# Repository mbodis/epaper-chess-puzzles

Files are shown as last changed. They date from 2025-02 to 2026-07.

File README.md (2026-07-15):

## Chess Puzzle Box with E-Paper Display
This project is a compact, battery-efficient chess puzzle box that uses an e-paper display and a push-button power switch for minimal power consumption. Puzzles are sourced from the Lichess puzzle database.

### Usage:

* First click: Shows a chess puzzle.
* Second click: Reveals the solution.

Perfect for practicing chess tactics on the go, with long battery life thanks to the low-power design.

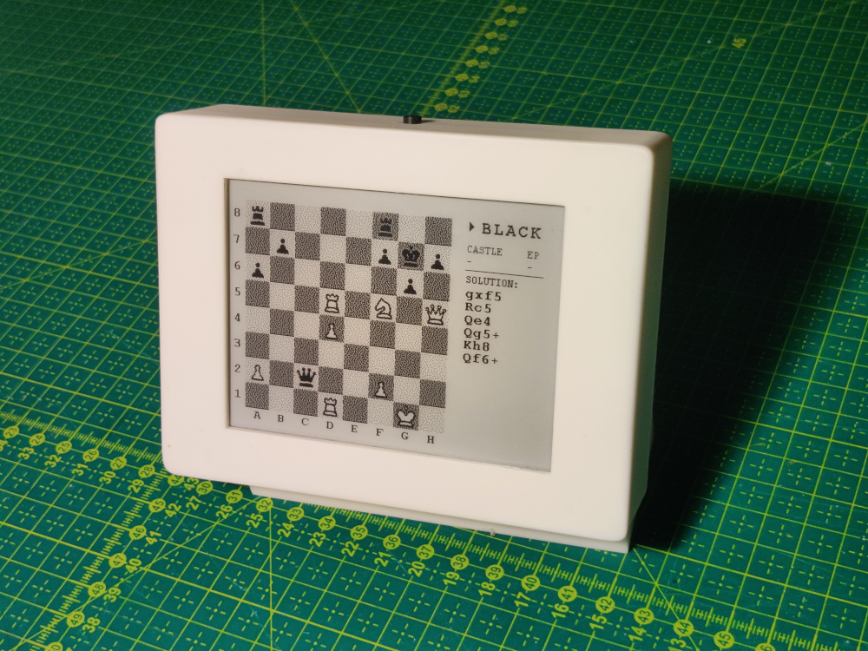
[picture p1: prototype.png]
image of chess box


## hardware setup

---
- 3.7 LiPo battery 
- 4.2 epaper wave share: https://www.waveshare.com/4.2inch-e-paper-module.htm
- adafruit logger RP2040: https://learn.adafruit.com/adafruit-feather-rp2040-adalogger/overview
- adafruit push-button power switch: https://www.adafruit.com/product/1400
- jump wires

## setup:

---
1. install arduino IDE https://www.arduino.cc/
2. install RP2040 board https://learn.adafruit.com/adafruit-feather-rp2040-adalogger/arduino (version 4.4.1)
3. install library for sd card: https://learn.adafruit.com/adafruit-feather-rp2040-adalogger/sd-card-2   
   - (note: 32 GB not working, 8GB working correctly)
4. setup epaper library (two options):

   **Option 1: Use included library (recommended)**
   - library supports **BOTH** 4.2" e-paper V1 and V2 displays
   - create symlink: `ln -s /path/to/repo/lib ~/Documents/Arduino/libraries/EPD4in2`
   - GPIO config is already set in `lib/DEV_Config.h` for Adalogger RP2040
   - to use V2 display, uncomment `#define USE_EPAPER_V2` in `ChessPuzzle.h`

   **Option 2: Download manually**
   - library supports **ONLY** 4.2" e-paper V1 displays
   - download from: https://www.waveshare.com/wiki/E-Paper_ESP8266_Driver_Board
   - copy into `~/Documents/Arduino/libraries/EPD4in2`
   - update `DEV_Config.h` to match board:
     ```
     // GPIO config Adalogger RP2040 with 4.2 waveshare epaper
     #define EPD_SCK_PIN  14
     #define EPD_MOSI_PIN 15
     #define EPD_CS_PIN   9
     #define EPD_RST_PIN  11
     #define EPD_DC_PIN   27
     #define EPD_BUSY_PIN 2
     ```
5. wire by attached scheme
6. install Python chess library for UCI to SAN conversion:
   ```bash
   pip3 install chess
   ```
7. generate puzzles and config by running `generate-puzzles.sh` (this will create puzzles and config in sd-card folder)
   - by default converts UCI notation to SAN notation (e.g., "e2e4" → "e4")
   - to skip conversion and keep UCI format: `./generate-puzzles.sh 1000 100 false`
   - copy content of sd-card folder into memory card (root folder)
8. select proper board and port in Arduino IDE
9. upload and enjoy

## SD card:

---
  - should contain `config.txt` file with two numbers. First is the number of lines. Second number of files.
  - should contain `counter.txt` file with one number. For beginnig it should be set to zero. Keep position in puzzles.
  - list of puzzles accordingly to config files puzzle-1.csv, puzzle-2.csv ... 
  - `solution.txt` is created automatically by the device after a puzzle is shown. It holds the current puzzle (in CSV format compatible with `puzzle-*.csv`) so that the next power-on can render the solution view. It is removed automatically after the solution is shown.

## how it works (two-boot flow):

---
The push-button power switch fully cuts power between clicks, so the device boots from scratch on every press:

1. **Boot 1 — puzzle**: no `solution.txt` on the SD card. The device reads the next puzzle from `puzzle-*.csv`, renders the chessboard, then writes the current puzzle data (id, FEN, solution, counter) into `solution.txt` and powers off.
2. **Boot 2 — solution**: `solution.txt` exists. The device reloads the puzzle data, re-renders the chessboard from the FEN as the "previous" frame, overlays the solution text, performs a partial refresh, deletes `solution.txt` and powers off.

## schema:

---
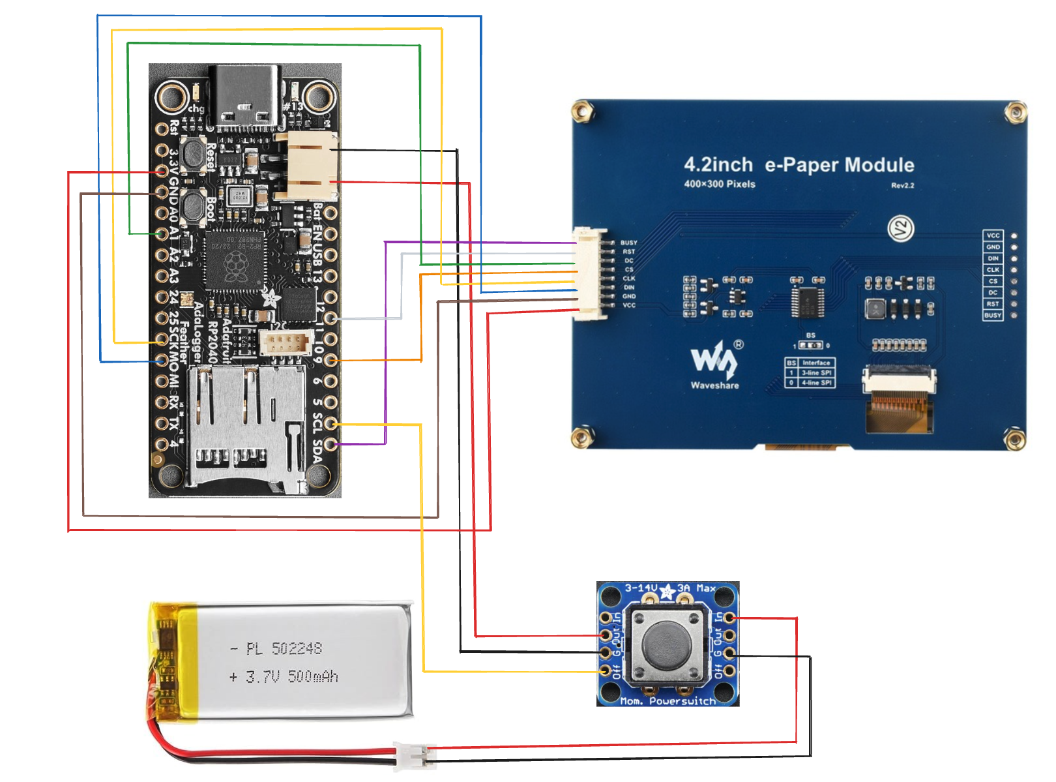
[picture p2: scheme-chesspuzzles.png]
image of schema


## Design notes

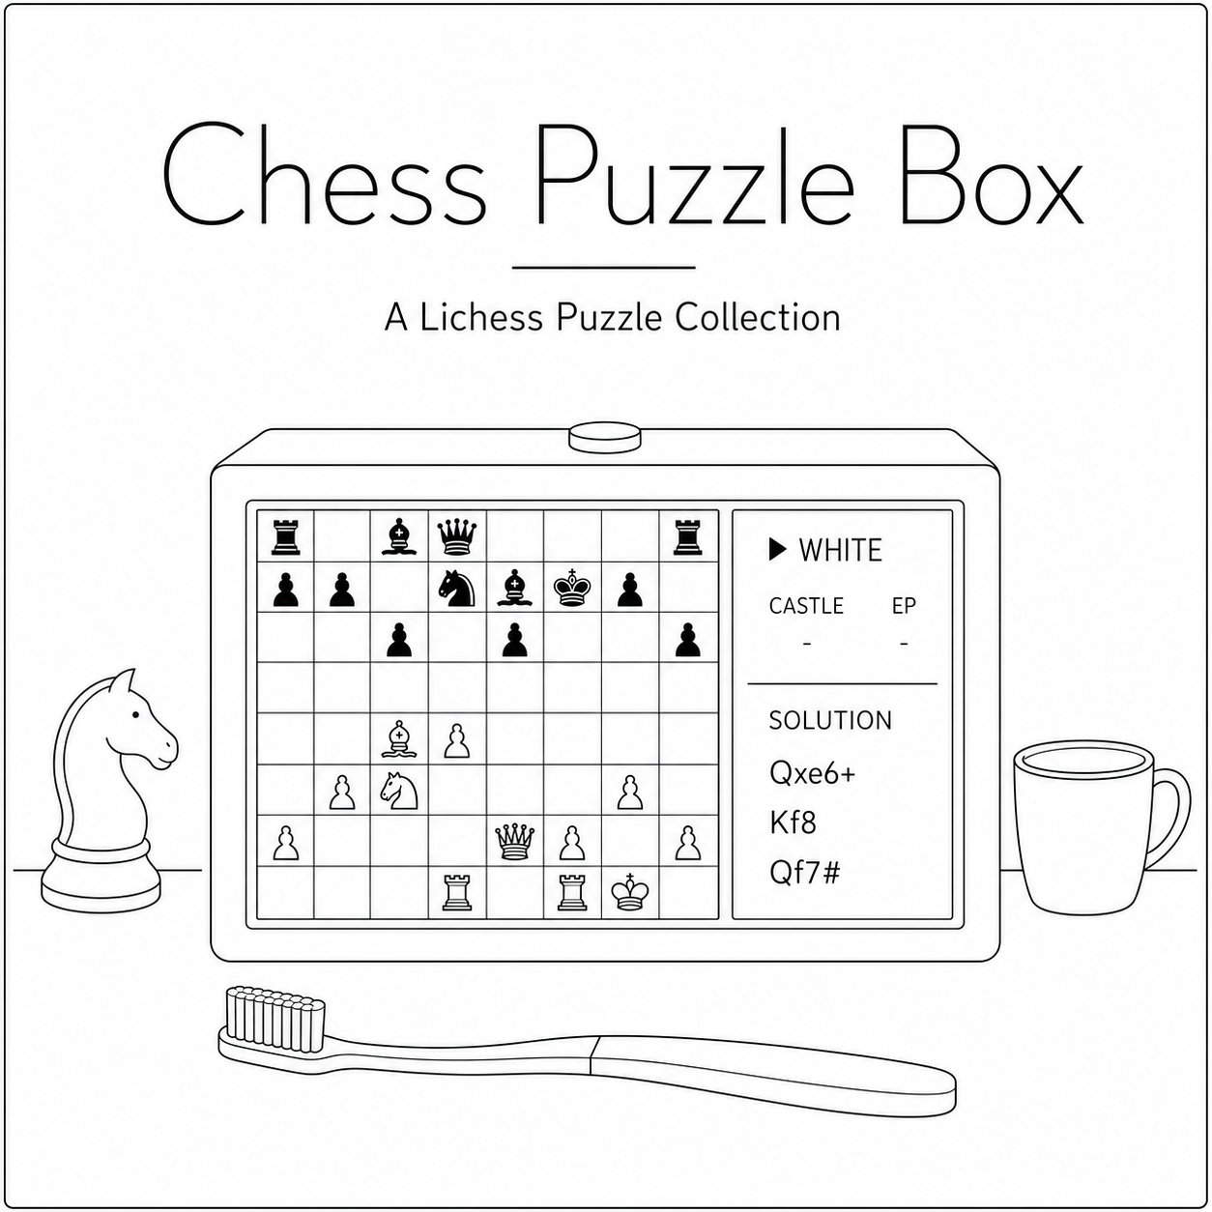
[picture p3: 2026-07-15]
res/box-cover-2.png

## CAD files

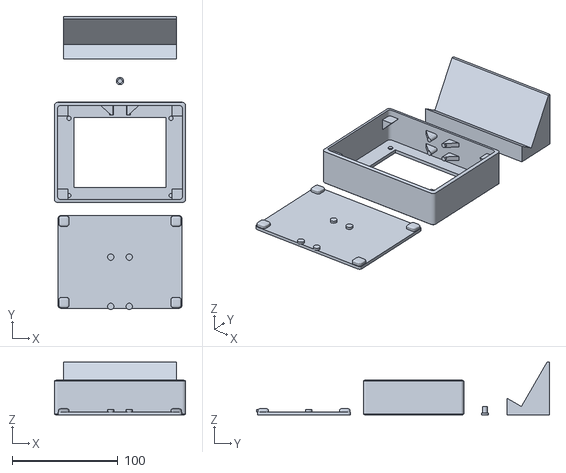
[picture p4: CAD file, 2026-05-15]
3d-model/ChessPuzzleBox2.0-full.stl
124.0 x 277.0 x 50.0

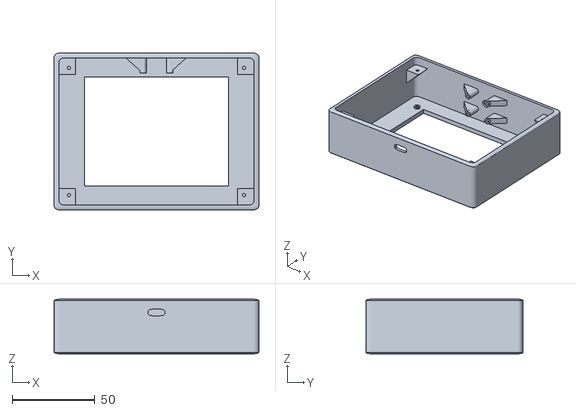
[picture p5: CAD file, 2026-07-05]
3d-model/ChessPuzzleBox2.0-case-front.stl
124.0 x 95.0 x 33.0

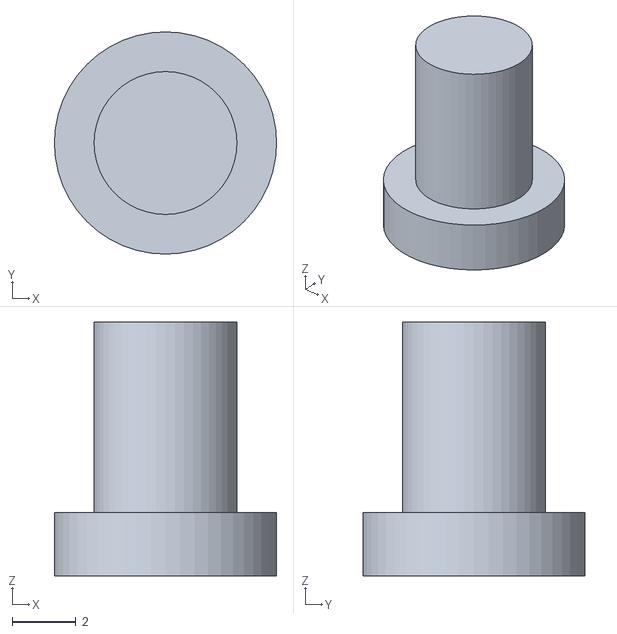
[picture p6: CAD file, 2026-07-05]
3d-model/ChessPuzzleBox2.0-case-btn.stl
7.00 x 7.00 x 8.00

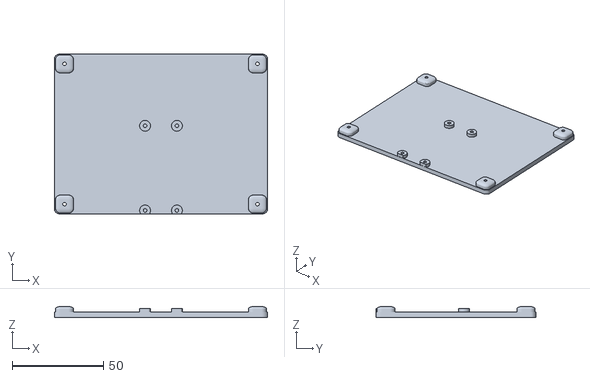
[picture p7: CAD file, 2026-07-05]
3d-model/ChessPuzzleBox2.0-case-back.stl
117.0 x 88.0 x 6.00

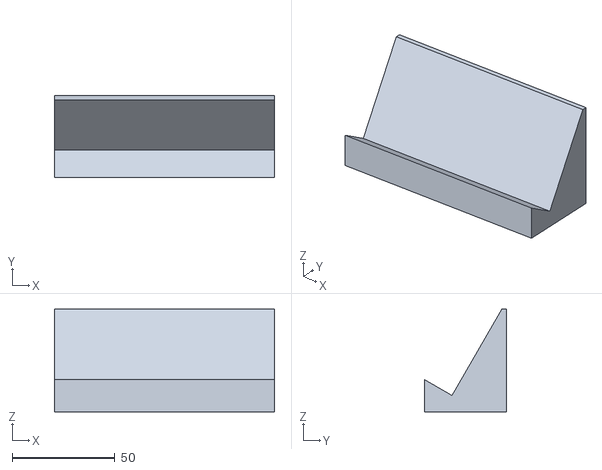
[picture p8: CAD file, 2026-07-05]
3d-model/ChessPuzzleBox2.0-stand.stl
107.0 x 40.0 x 50.0

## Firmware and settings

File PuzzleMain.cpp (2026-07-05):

#include "PuzzleMain.h"
#include "CsvParser.h"
#include <string.h>
#include <stdlib.h>

PuzzleMain::PuzzleMain() {
  Serial.println("[PuzzleMain] -- start --");

  SD = Utils::initSdCard();

  if (this->hasSolutionFile()) {
    this->readSolution();
    this->puzzle.init();
    this->puzzle.printToLog();
    this->puzzle.drawSolution();
    this->deleteFileWithSolution();
  } else {
    CsvParser parser;
    if (parser.getPuzzle(&this->puzzle)) {
      this->puzzle.init();
      this->puzzle.printToLog();
      this->puzzle.drawChessboard();
      if (!this->puzzle.isMessage){
        this->createFileWithSolution();
      }
    }
  }

  Serial.println("[PuzzleMain] -- end --");
}

// render all - debug only
// PuzzleMain::PuzzleMain() {
//   Serial.println("[PuzzleMain] renderAll -- start --");
//   CsvParser parser;
//   if (parser.getPuzzle(&this->puzzle)) {
//     this->puzzle.init();
//     this->puzzle.printToLog();
//     this->puzzle.drawChessboard();
//     this->puzzle.drawSolution();
//   }
//   Serial.println("[PuzzleMain] renderAll -- end --");
// }

bool PuzzleMain::hasSolutionFile() {
  bool exists = SD.exists(this->SOLUTION_FILE);
  Serial.printf("[PuzzleMain] %s \n", exists ? "draw solution" : "draw new puzzle");
  return exists;
}

void PuzzleMain::readSolution() {
  Serial.println("[PuzzleMain] readSolution");
  // TODO need to re init SD card ?!?
  SdFat SD = Utils::initSdCard();

  File32 myFile = SD.open(this->SOLUTION_FILE);
  if (!myFile) {
    Serial.println("[PuzzleMain] ERR: cannot open solution file");
    return;
  }

  if (!myFile.available()) {
    Serial.println("[PuzzleMain] ERR: solution file empty");
    myFile.close();
    return;
  }

  int n = myFile.fgets(this->solutionLine, sizeof(this->solutionLine));
  myFile.close();
  if (n <= 0) {
    Serial.println("[PuzzleMain] ERR: fgets failed");
    return;
  }
  if (this->solutionLine[n - 1] != '\n' && n == (int)(sizeof(this->solutionLine) - 1)) {
    Serial.println("[PuzzleMain] ERR: line too long");
  }
  // Strip trailing newline
  if (n > 0 && this->solutionLine[n - 1] == '\n') {
    this->solutionLine[n - 1] = '\0';
  }

  // Snapshot the line first because CsvParser::parseLine mutates it via
  // strtok and we still need to extract the trailing puzzleCounter field.
  char counterCopy[sizeof(this->solutionLine)];
  strncpy(counterCopy, this->solutionLine, sizeof(counterCopy));
  counterCopy[sizeof(counterCopy) - 1] = '\0';

  CsvParser::parseLine(&this->puzzle, this->solutionLine);

  // The saved line has the format: id,FEN,solution,puzzleCounter
  // Extract the 4th comma-separated field.
  char *tok = strtok(counterCopy, ",");
  int idx = 0;
  this->puzzle.puzzleCounter = 1;  // safe default (non-zero, not multiple of 1000)
  while (tok != nullptr) {
    if (idx == 3) {
      this->puzzle.puzzleCounter = atol(tok);
      break;
    }
    tok = strtok(nullptr, ",");
    idx++;
  }
}

void PuzzleMain::deleteFileWithSolution() {
  bool deleted = false;
  if (SD.exists(this->SOLUTION_FILE)) {
    deleted = SD.remove(this->SOLUTION_FILE);
  }
  Serial.printf("[PuzzleMain] solution file %s \n", deleted ? "deleted" : "not deleted");
}

void PuzzleMain::createFileWithSolution() {
  // Persist full puzzle state in CSV-compatible format so that on the next
  // power-on (when only the solution file is present) drawSolution() can
  // rebuild the chessboard from FEN.
  //
  // Line format (compatible with CsvParser::parseLine):
  //   id,<placement> <w|b> <castling> <enpassant> 0 1,solution,puzzleCounter
  //
  // The "0 1" are FEN halfmove clock + fullmove number placeholders -
  // CsvParser::parseLine ignores those two fields.
  File32 myFile = SD.open(this->SOLUTION_FILE, FILE_WRITE);
  myFile.print(this->puzzle.id);
  myFile.print(",");
  myFile.print(this->puzzle.fenNotation);
  myFile.print(" ");
  myFile.print(this->puzzle.whiteIsOnTheMove ? "w" : "b");
  myFile.print(" ");
  myFile.print(this->puzzle.castlingAvailability);
  myFile.print(" ");
  myFile.print(this->puzzle.enPassant);
  myFile.print(" 0 1,");
  myFile.print(this->puzzle.solution);
  myFile.print(",");
  myFile.print(this->puzzle.puzzleCounter);
  myFile.print("\n");
  bool success = myFile.close();
  Serial.printf("[PuzzleMain] solution: %s \n", this->puzzle.solution);
  Serial.printf("[PuzzleMain] createFileWithSolution %s \n", success ? "success" : "failed");
}

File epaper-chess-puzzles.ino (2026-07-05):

#include "PuzzleMain.h"
#include <Arduino.h>

/*
 * using power button from adafruit
 * using pin to power off device programatically
 */
const int POWER_OFF_PIN = 3;

void setup() {
  pinMode(POWER_OFF_PIN, OUTPUT);  // sets the digital pin as output

  Serial.begin(115200);
  delay(100);

  PuzzleMain puzzleMain;
  digitalWrite(POWER_OFF_PIN, HIGH);
}

void loop() {
  // no loop action
}

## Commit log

2025-02-04 feat: draw puzzle/result
    [config.txt, puzzle-0.csv]
2025-03-19 feat: add 3d model of case
    [ChessPuzzleBox-full.stl]
2025-03-27 feat(3d-model): add stand for puzzle box
    [ChessPuzzleBox-full.stl]
2026-01-02 feat: improve solution output - enlarge solution redraw box - filter out puzzles that has more than 13 steps as solution
2026-05-15 chore: add arduino config
2026-05-15 feat: improved 3d model - case
    [ChessPuzzleBox-full-2.0.stl, ChessPuzzleBox-full.stl]
2026-05-20 Revert "chore: refactoring"
    This reverts commit 0db005339a98314c68dbde3333a3e3f2ea60f000.
    [ChessPuzzle.cpp, CsvParser.cpp, PuzzleMain.cpp]
2026-05-22 feat(deps): include EPD4in2 library in repository
    - Add EPD4in2 library files to lib/ folder
    - Update includes to use Arduino library system
    - Add symlink setup instructions to README
    - Disable V2 display support (not currently used)
2026-05-25 feat(v2): partial-refresh solution view via FEN persistence
    After a power cycle the SSD168x V2 controller SRAM is undefined, so the
    existing windowed partial refresh produced noise across the whole panel.
    Persist full puzzle state (id, FEN, solution, counter) to solution.txt
    on boot 1 and reload it on boot 2 so the MCU can rebuild the chessboard
    that is physically on the panel. Then drive a diff-based partial refresh
    that writes the previous frame to plane 0x26 and the new frame (chessboard
    + solution overlay) to 0x24 over the full panel. Pixels where old == new
    get no waveform pulse, leaving the chessboard untouched and updating only
    the solution rectangle.
    - ChessPuzzle: extract renderCh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
    [ChessPuzzle.cpp, CsvParser.cpp, PuzzleMain.cpp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]
2026-07-05 Convert solution display from UCI to SAN notation
    - Add ChessBoard::getPieceAt() to get piece at square position
    - Add ChessBoard::makeMove() to execute UCI moves on board
    - Add ChessPuzzle::convertSolutionToSan() for UCI to SAN conversion
    - Update drawSolution() to display SAN notation instead of UCI
    Supported features:
    - Basic moves (e2e4 → e4, g1f3 → Nf3)
    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
2026-07-05 fix: make bigger redraw screen part for v1 version
    [ChessPuzzle.cpp]
2026-07-05 feat: add 3d models
    [ChessPuzzleBox2.0-case-back.stl, ChessPuzzleBox2.0-case-btn.stl, ChessPuzzleBox2.0-case-front.stl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]
2026-07-15 feat: san format in solution - revert changes - attempt to uci-to-san format - use chess python lib to transfer to san format
    [ChessPuzzle.cpp]
